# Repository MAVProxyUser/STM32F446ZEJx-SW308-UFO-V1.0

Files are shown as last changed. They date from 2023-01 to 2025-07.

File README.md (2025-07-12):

STM32F446ZEJx UFBGA144 Target Board for ChipWhisperer

* [STM32F446ZEJx-SW308-UFO-V1.0](#stm32f446zejx-sw308-ufo-v10)
   * [Jumpers](#jumpers)
   * [Schematic](#schematic)
   * [Testing Blanks &amp; Real Paprium](#testing-blanks--real-paprium)

It is no secret that I am affiliated with the group of people focusing on [efforts to dump the Watermelon Games Paprium cart](https://github.com/ArcadeHustle/WatermelonPapriumDump). As part of this effort there became a need to 
attack an STM32F4 based chip. Sadly that chip wound up being in RDP2 mode, but the resulting tool that was created serves a greater purpose, so it is being shared here. 

At the time the work effort was put forth there was no UFBGA144 compatible Target Board for ChipWhisperer, so we worked with a trusted PCB design partner [@javier-rodas](https://github.com/javier-rodas) owner of SEVENIX INGENIERIA & the [@XTREME-MISTER](https://github.com/XTREME-MISTER) project to work out what was needed. This board will connect easily to a STLink V2, 
or a ChipWhisperer depending on where the jumpers are placed. The initial project this board was created for never moved past the STLink jumpers, we immediatly found that the chip was fully protected with all debug interfaced 
disabled. 

None the less, this is a perfect platform for learning Chip Whisperer based glitching logic, or attacking other UFBGA144 STM32 chips. 

# STM32F446ZEJx-SW308-UFO-V1.0

[Documentation](https://github.com/MAVProxyUser/STM32F446ZEJx-SW308-UFO-V1.0/tree/main/STM32F446ZEJx-SW308-UFO%20V1.0/DOCS) is fairly simple, set the jumpers accordingly, treat it as you would any other ChipWhisperer target board. 

## Jumpers
Enable jumpers as follows for CW usage. 
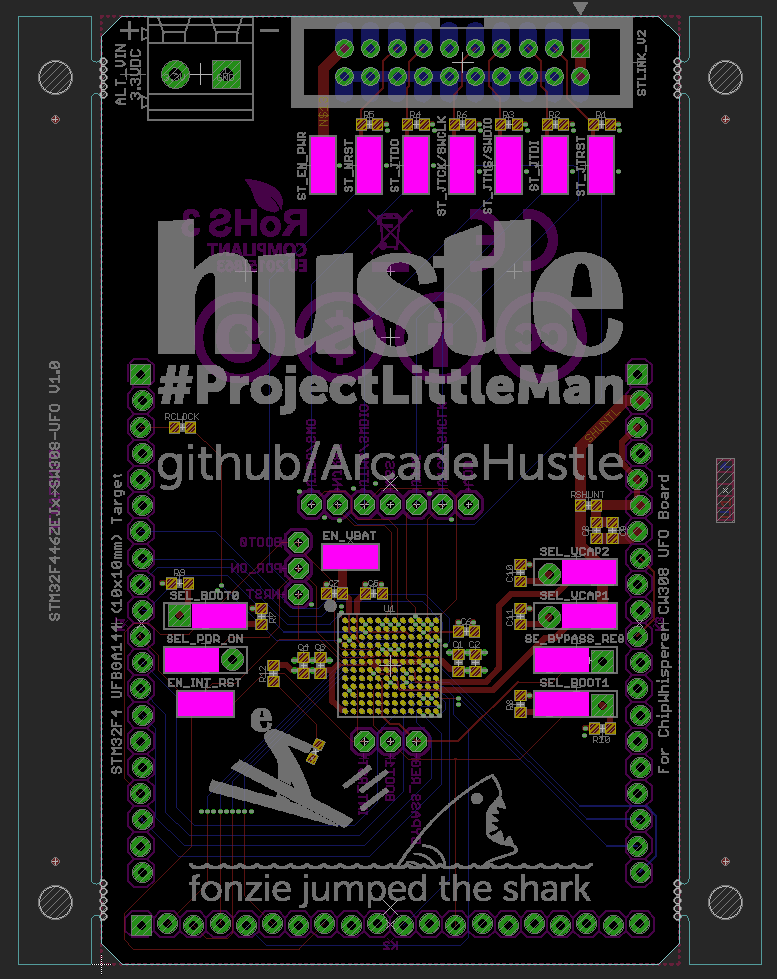
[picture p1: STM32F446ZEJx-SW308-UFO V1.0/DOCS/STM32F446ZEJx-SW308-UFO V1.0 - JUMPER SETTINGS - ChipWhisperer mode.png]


## Schematic
You can see how the jumpers impact the schematic below.  
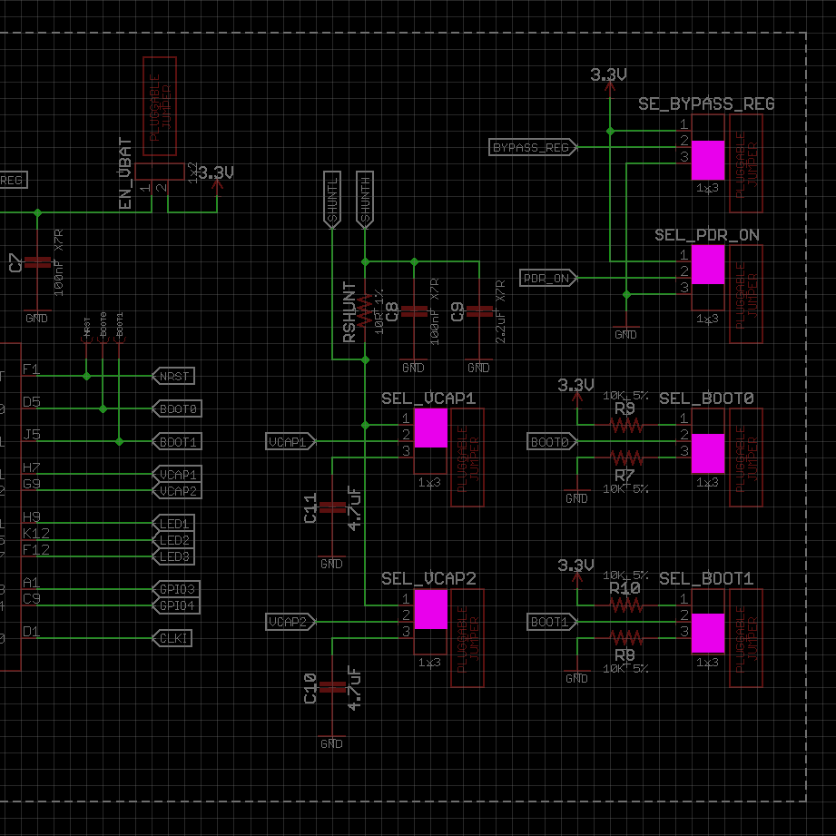
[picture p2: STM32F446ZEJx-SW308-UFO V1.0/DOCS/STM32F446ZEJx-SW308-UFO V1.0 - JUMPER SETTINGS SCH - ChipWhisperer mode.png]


## Testing Blanks & Real Paprium 
We tested this design with a number of now rare blank STM32F446ZEJ6 chips, as well as an excavated STM32 from a Paprium game cart. 
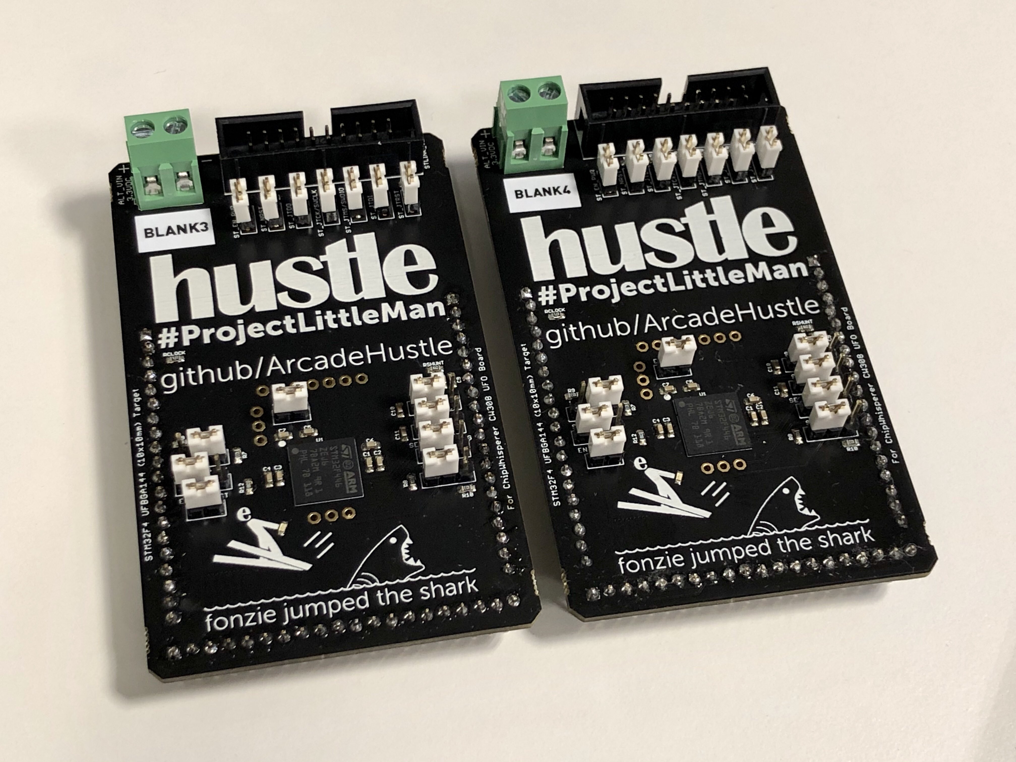
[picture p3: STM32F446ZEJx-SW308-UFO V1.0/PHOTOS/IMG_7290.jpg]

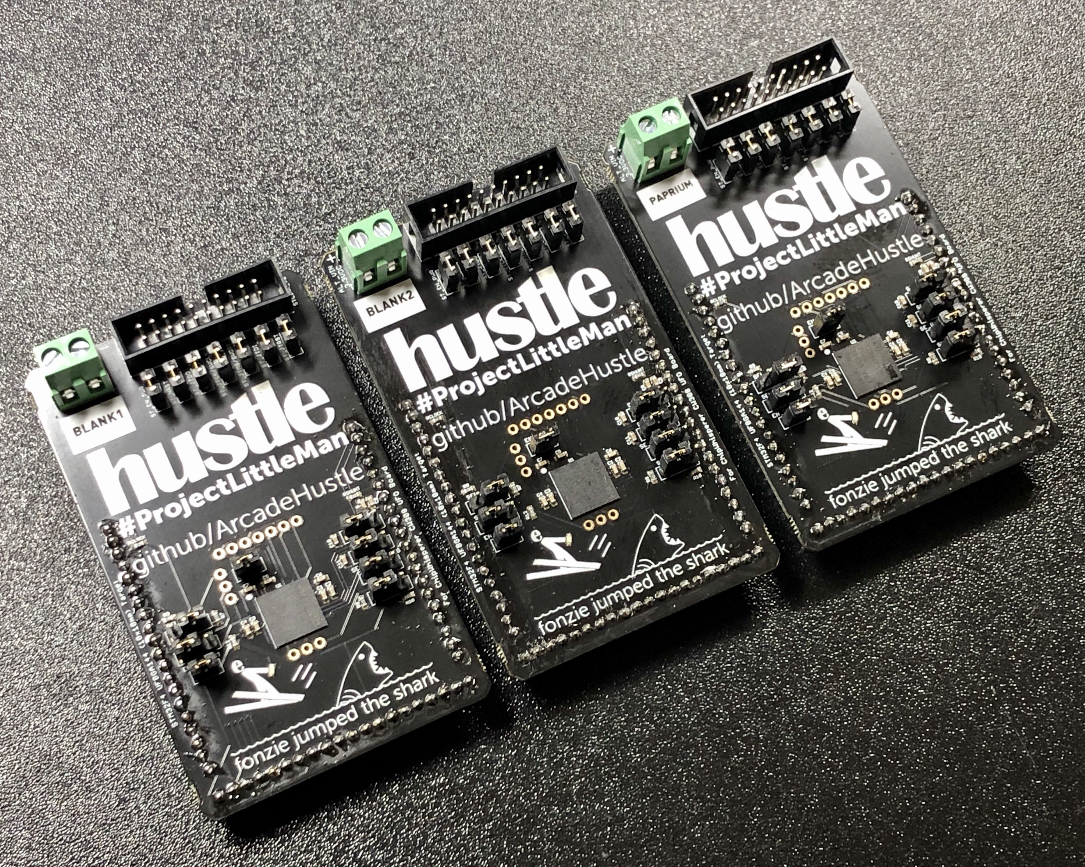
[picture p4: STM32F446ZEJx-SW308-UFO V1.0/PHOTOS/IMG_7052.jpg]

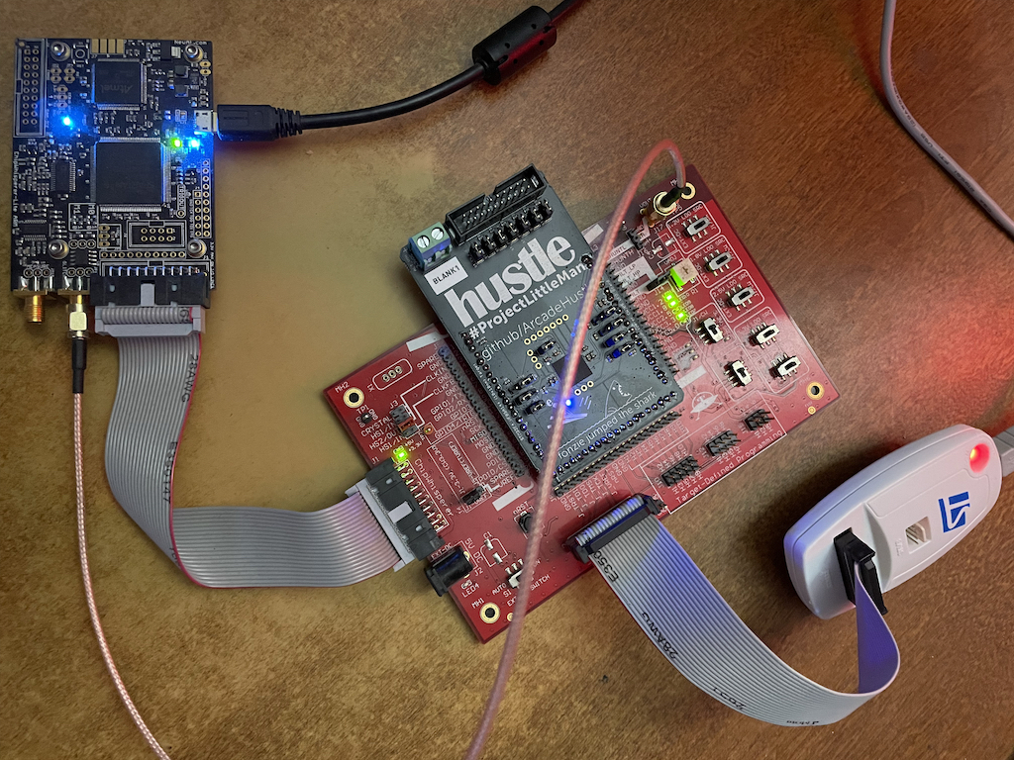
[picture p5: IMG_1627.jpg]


If you need an amazing PCB designer, please let me know, and I can put you in touch with one.

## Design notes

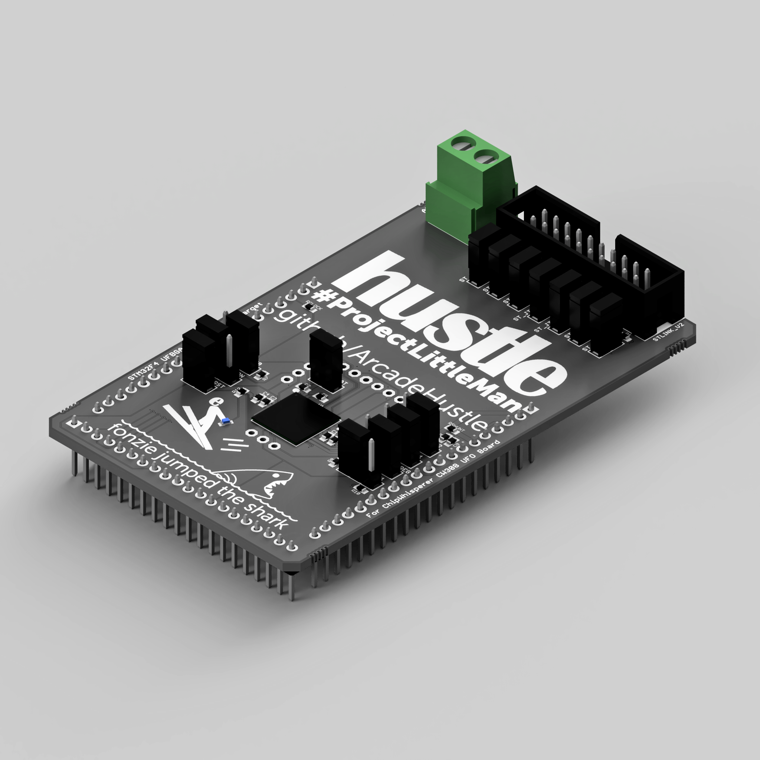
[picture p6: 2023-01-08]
STM32F446ZEJx-SW308-UFO V1.0/RESOURCES/STM32F446ZEJx-SW308-UFO V1.0 - 3.PNG

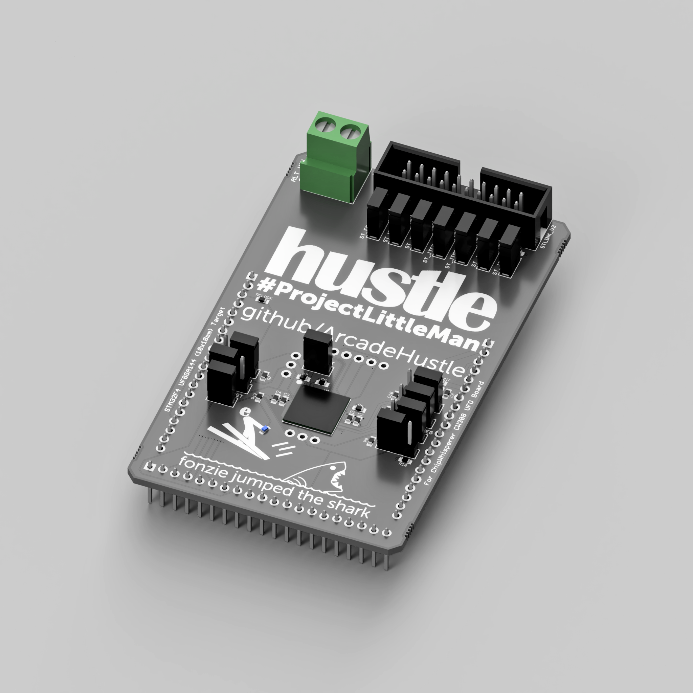
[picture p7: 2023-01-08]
STM32F446ZEJx-SW308-UFO V1.0/RESOURCES/STM32F446ZEJx-SW308-UFO V1.0 - 2.PNG

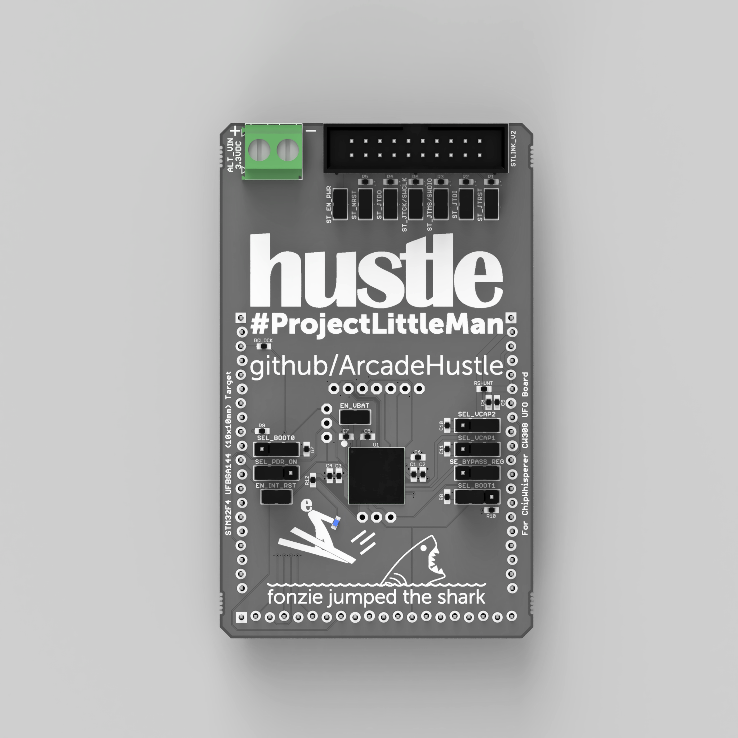
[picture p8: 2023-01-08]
STM32F446ZEJx-SW308-UFO V1.0/RESOURCES/STM32F446ZEJx-SW308-UFO V1.0 - 1.PNG

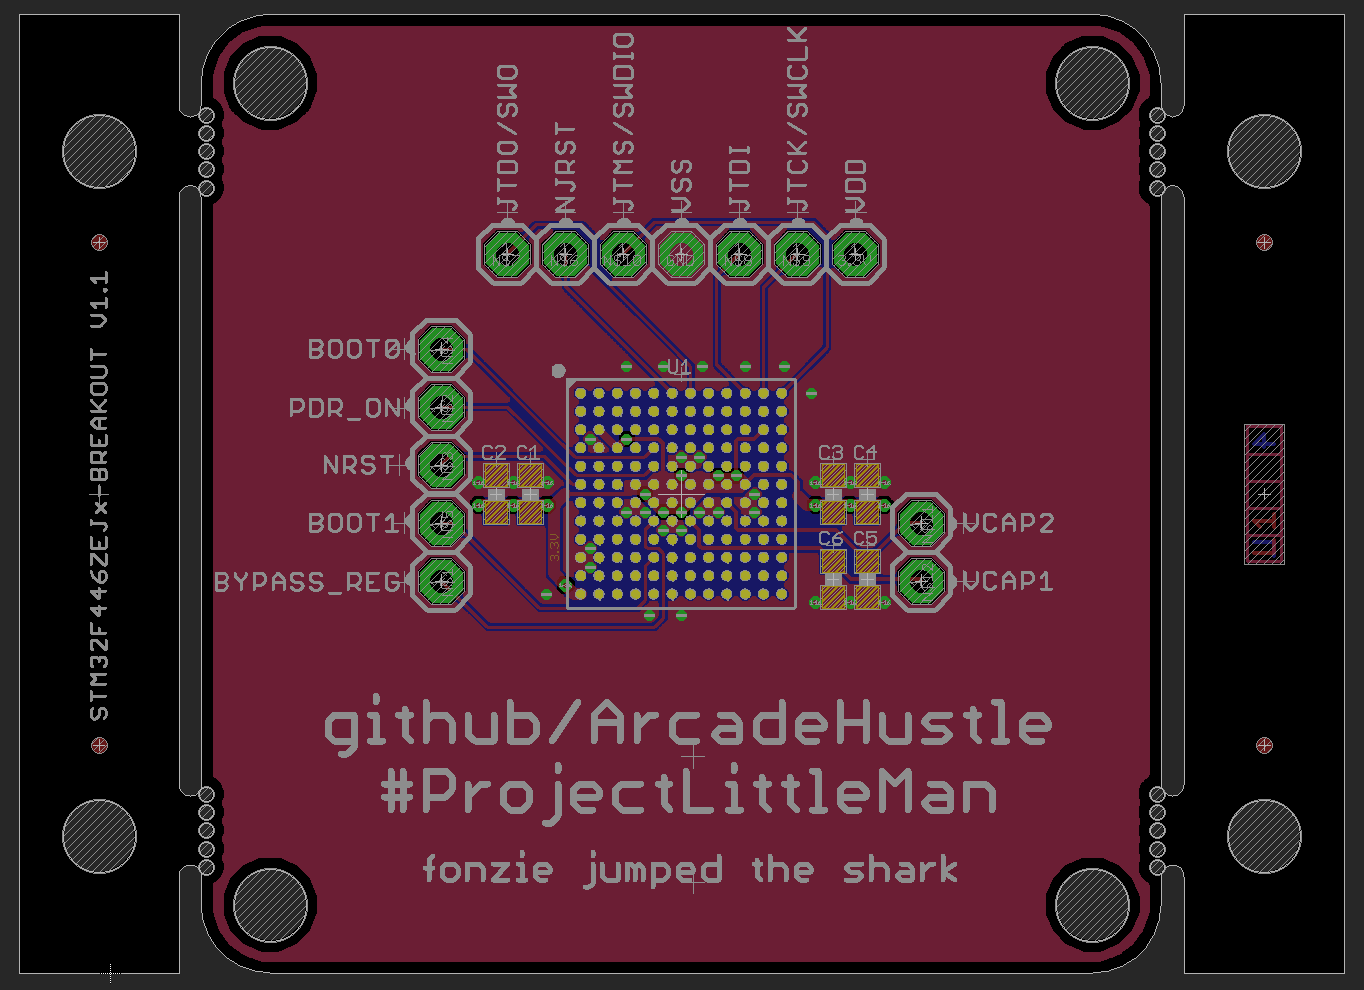
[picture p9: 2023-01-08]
failed_attempts/STM32F446ZEJx-BREAKOUT V1.1/STM32F446ZEJx-BREAKOUT V1.1 - PREVIEW.png

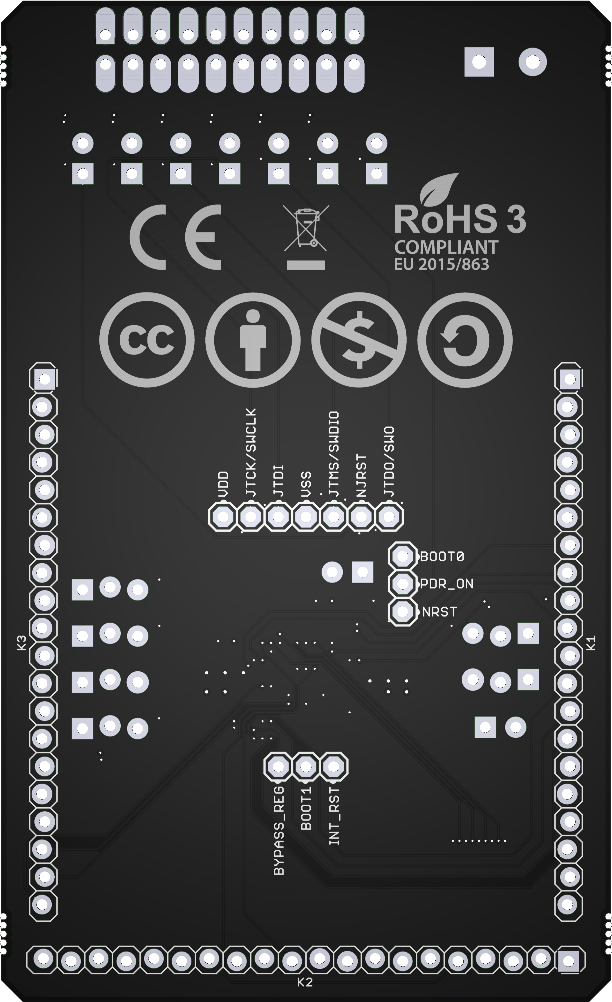
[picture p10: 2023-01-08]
STM32F446ZEJx-SW308-UFO V1.0/RESOURCES/STM32F446ZEJx-SW308-UFO V1.0 - PREVIEW BOTTOM.png

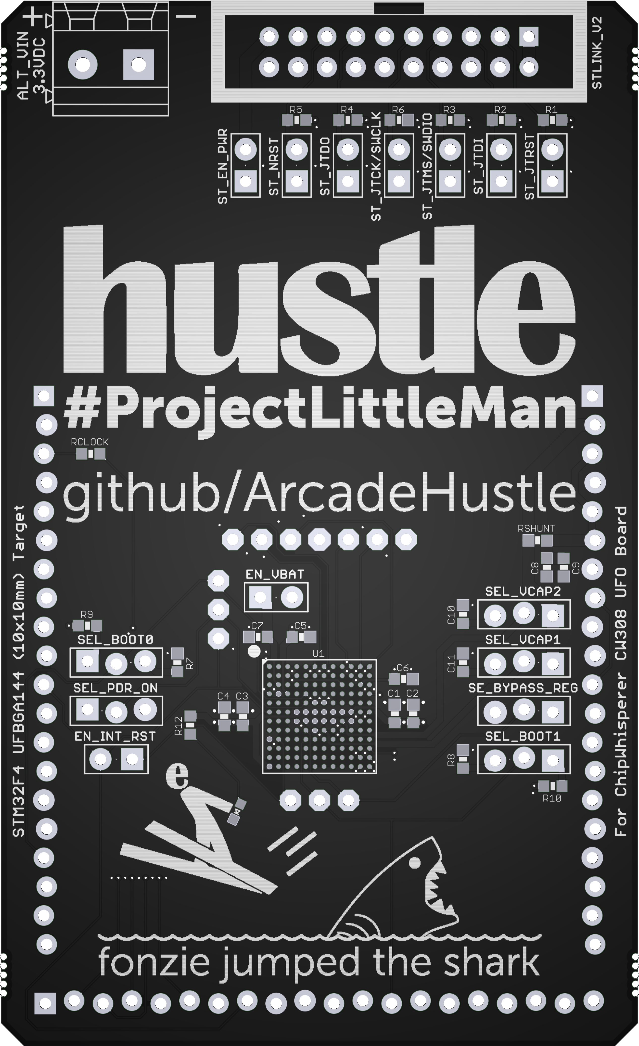
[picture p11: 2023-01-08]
STM32F446ZEJx-SW308-UFO V1.0/RESOURCES/STM32F446ZEJx-SW308-UFO V1.0 - PREVIEW TOP.png

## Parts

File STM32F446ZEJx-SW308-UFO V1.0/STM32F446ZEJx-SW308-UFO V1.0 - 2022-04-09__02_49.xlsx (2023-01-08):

PROJECT NAME |  | STM32F446ZEJx-SW308-UFO V1.0
REVISION DATE |  | 2022-09-04 02:49
Qt (req.) | Min\Mult Order Qty | Qt (min) | Unit Price (USD) | Order Req. Price (USD) | Order Min. Price (USD) | Quantity Available (4/9/2022) | LCSC_PN | Minimum Specification | Package | RoHS | Manufacturer | Manufacturer Part Number | Designator
8 | 100\100 | 100 | $0.0028 | $0.0224 | $0.2800 | 25988600 | C1591 | 100nF X7R | 0603_IPC_NOMINAL | Y | Samsung Electro-Mechanics | CL10B104KB8NNNC | C1, C2, C3, C4, C5, C6, C7, C8
10 | 100\100 | 100 | $0.0011 | $0.0110 | $0.1100 | 33697600 | C99198 | 10K 5% | 0603_IPC_NOMINAL | Y | YAGEO | RC0603JR-0710KL | R1, R2, R3, R4, R5, R6, R7, R8, R9, R10
1 | 100\100 | 100 | $0.0012 | $0.0012 | $0.1200 | 881600 | C109318 | 10R 1% | 0603_IPC_NOMINAL | Y | YAGEO | RC0603FR-0710RL | RSHUNT
1 | 100\100 | 100 | $0.0014 | $0.0014 | $0.1400 | 7905100 | C22548 | 1K | 0603_IPC_NOMINAL | Y | YAGEO | RC0603FR-071KL | R12
9 | 20\20 | 20 | $0.0282 | $0.2538 | $0.5640 | 34260 | C124375 | 1x2 | M1X2 | Y | Ckmtw(Shenzhen Cankemeng) | C124375 | EN_INT_RST, EN_VBAT, ST_EN_PWR, ST_JTCK/SWCLK, ST_JTDI, ST_JTDO, ST_JTMS/SWDIO, ST_JTRST, ST_NRST
3 | 5\5 | 5 | $0.1047 | $0.3141 | $0.5235 | 15930 | C50981 | 1x20 | M1X20 | Y | BOOMELE(Boom Precision Elec) | C50981 | K1, K2, K3
6 | 50\50 | 50 | $0.0148 | $0.0888 | $0.7400 | 100 | C49257 | 1x3 | M1X3 | Y | BOOMELE(Boom Precision Elec) | C49257 | SEL_BOOT0, SEL_BOOT1, SEL_PDR_ON, SEL_VCAP1, SEL_VCAP2, SE_BYPASS_REG
1 | 50\50 | 50 | $0.0150 | $0.0150 | $0.7500 | 284250 | C100082 | 2.2uF X7R | 0603_IPC_NOMINAL | Y | Samsung Electro-Mechanics | CL10B225KP8NNNC | C9
1 | 5\5 | 5 | $0.1239 | $0.1239 | $0.6195 | 53305 | C8465 | 2P_5.08MM | 2X5.08MM | Y | Ningbo Kangnex Elec | WJ500V-5.08-2P | ALT_VIN
2 | 50\50 | 50 | $0.0042 | $0.0084 | $0.2100 | 7109400 | C8032 | 4.7uF X5R | 0603_IPC_NOMINAL | Y | Samsung Electro-Mechanics | CL10A475KQ8NNNC | C10, C11
1 | 100\100 | 100 | $0.0013 | $0.0013 | $0.1300 | 584800 | C114628 | 51R 1% | 0603_IPC_NOMINAL | Y | YAGEO | RC0603FR-0751RL | RCLOCK
1 | 20\20 | 20 | $0.0209 | $0.0209 | $0.4180 | 260520 | C72041 | BLUE | 0603-BLUE-LED | Y | Everlight Elec | 19-217/BHC-ZL1M2RY/3T | PWR
1 | 5\5 | 5 | $0.0976 | $0.0976 | $0.4880 | 8905 | C429961 | IDC20 | M2X10_2.54MM_IDC_SHROUDED | Y | JLIN | 321020SG0ABK00A01 | STLINK_V2
15 | 50\50 | 50 | $0.0076 | $0.1140 | $0.3800 | 910600 | C5305 | JUMPER_2.54MM | JUMPER_2.54MM | Y | BOOMELE(Boom Precision Elec) | C5305 | JUMPER1, JUMPER2, JUMPER3, JUMPER4, JUMPER5, JUMPER6, JUMPER7, JUMPER8, JUMPER9, JUMPER10, JUMPER11, JUMPER12, JUMPER13, JUMPER14, JUMPER15
 |  | 1 | $3.0000 |  | $3.0000 |  |  | Handling fee (order <$18)
 |  |  |  | $1.07 | $8.47
 |  |  |  |  | $43.70 | DHL Express shipping (3-7 days)
 |  |  |  |  | $52.17 | TOTAL

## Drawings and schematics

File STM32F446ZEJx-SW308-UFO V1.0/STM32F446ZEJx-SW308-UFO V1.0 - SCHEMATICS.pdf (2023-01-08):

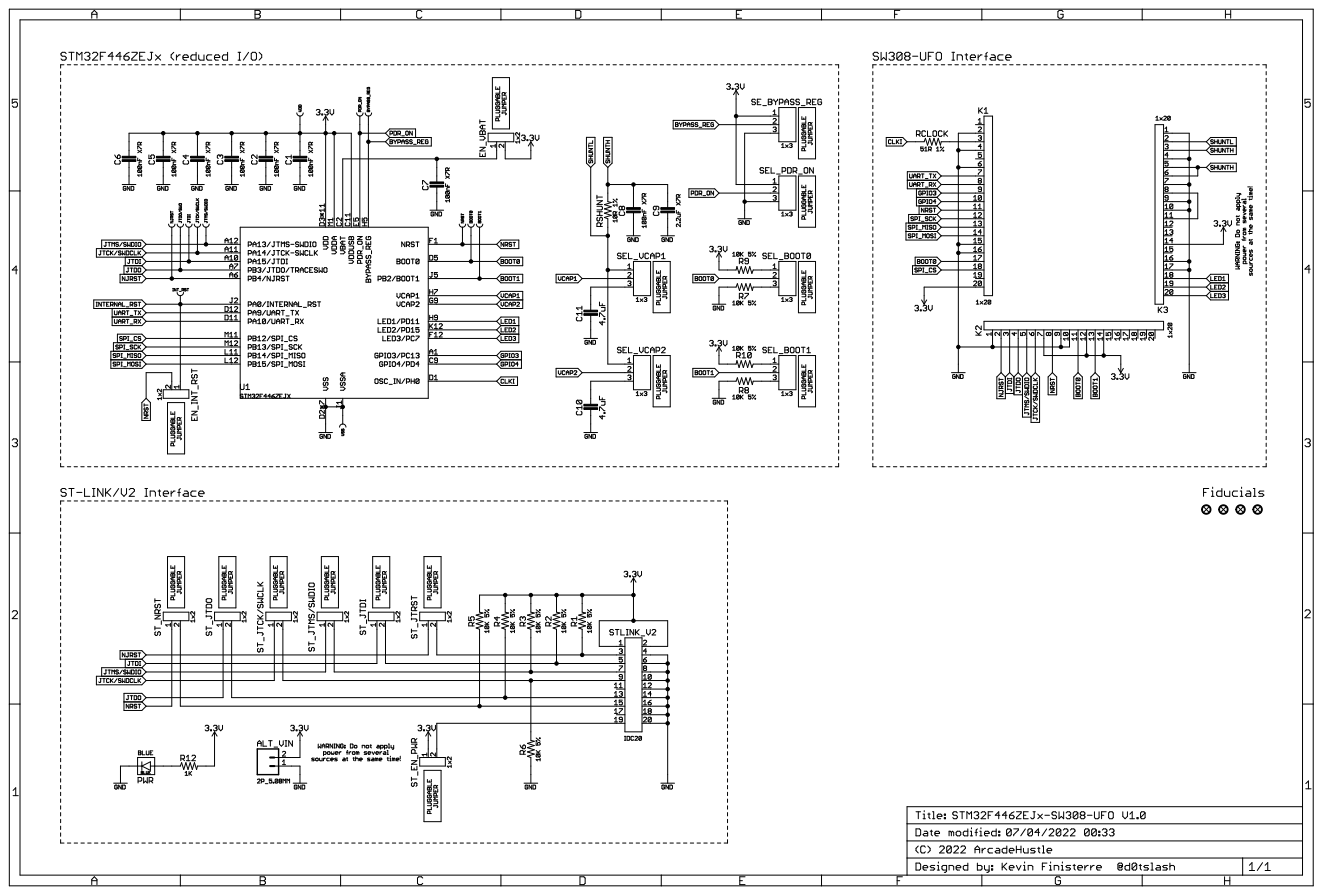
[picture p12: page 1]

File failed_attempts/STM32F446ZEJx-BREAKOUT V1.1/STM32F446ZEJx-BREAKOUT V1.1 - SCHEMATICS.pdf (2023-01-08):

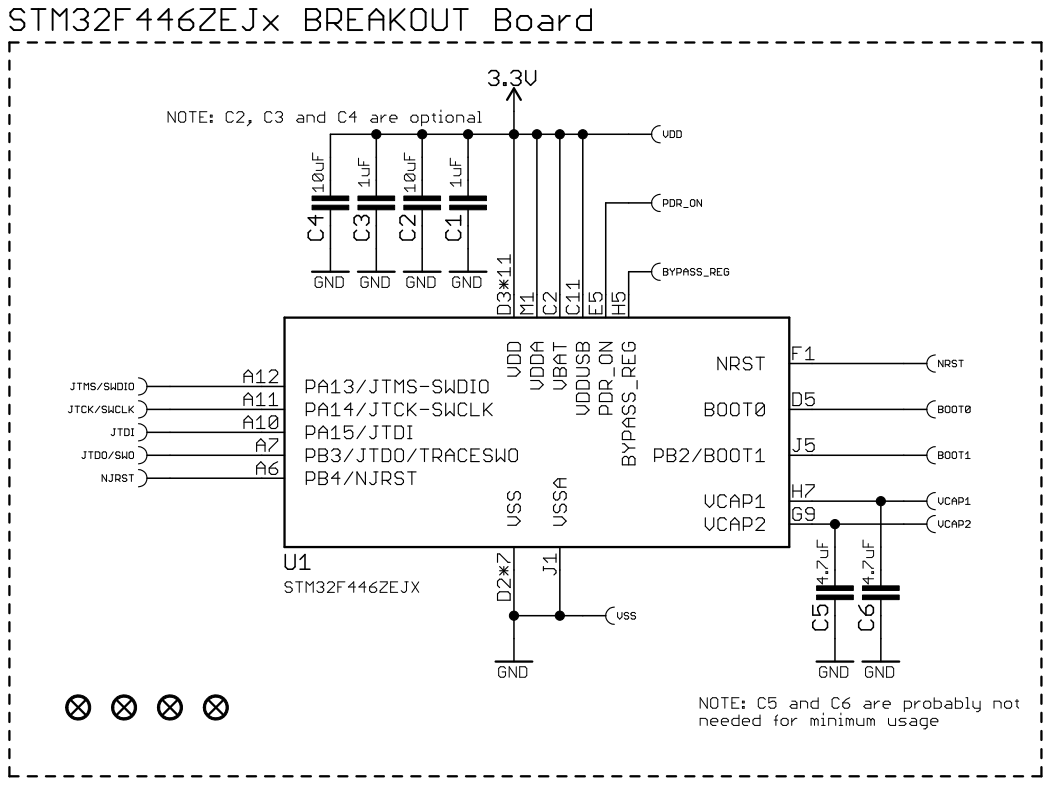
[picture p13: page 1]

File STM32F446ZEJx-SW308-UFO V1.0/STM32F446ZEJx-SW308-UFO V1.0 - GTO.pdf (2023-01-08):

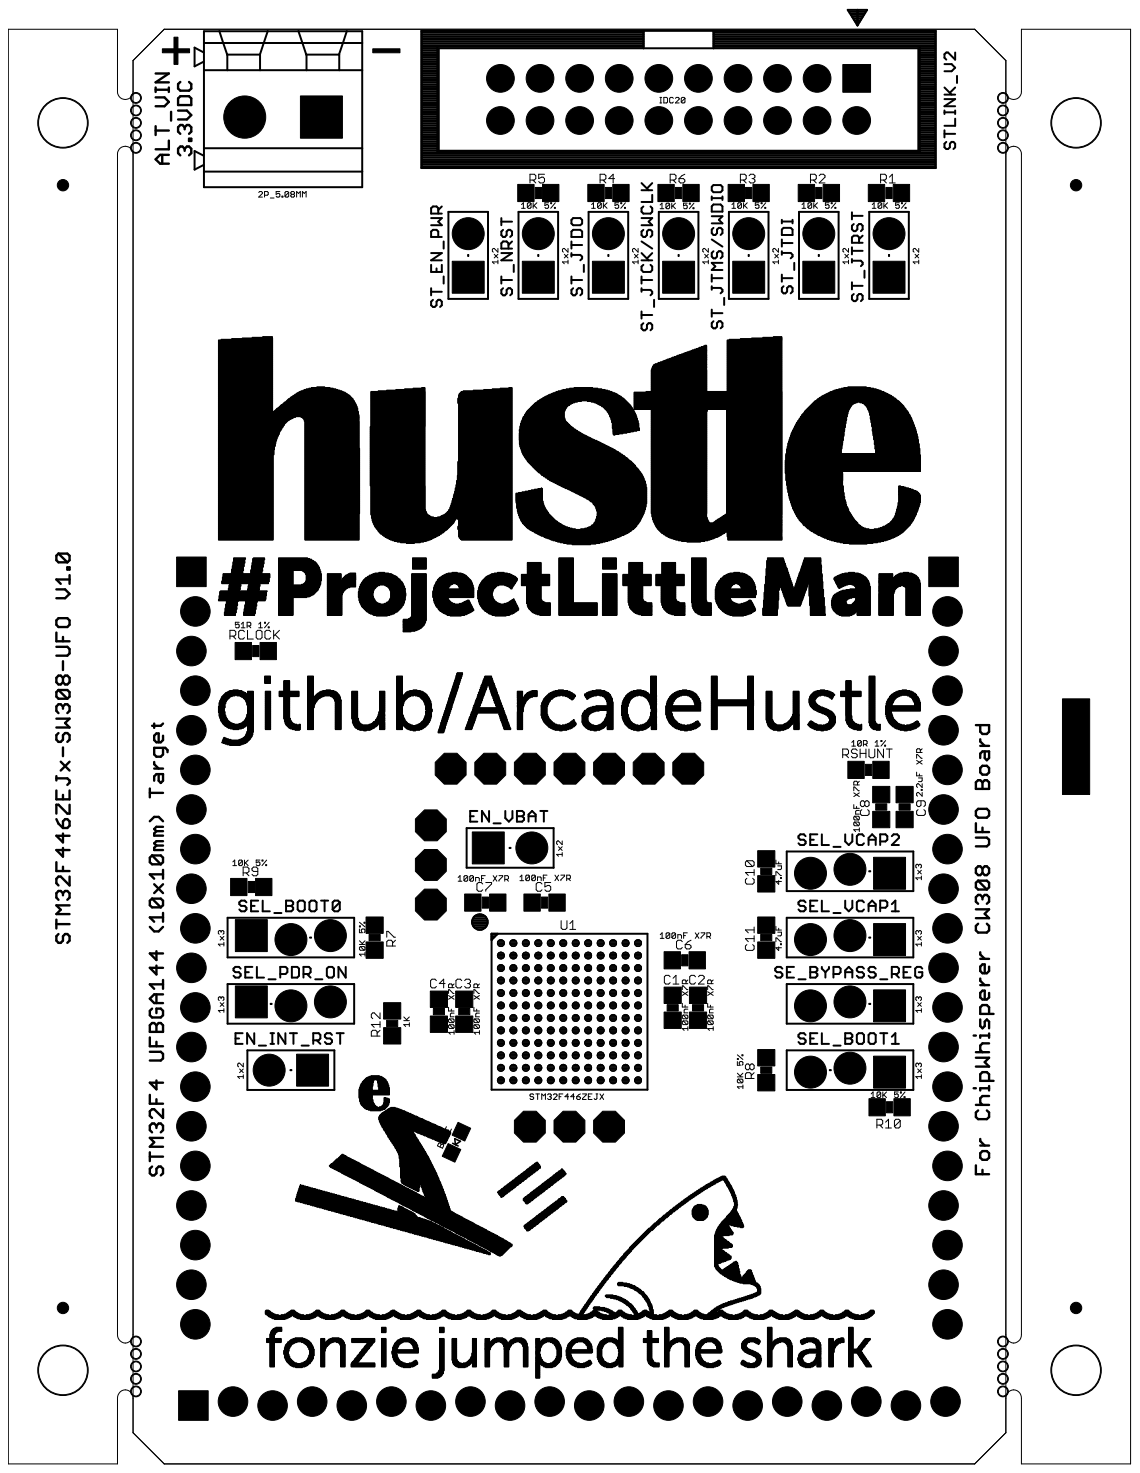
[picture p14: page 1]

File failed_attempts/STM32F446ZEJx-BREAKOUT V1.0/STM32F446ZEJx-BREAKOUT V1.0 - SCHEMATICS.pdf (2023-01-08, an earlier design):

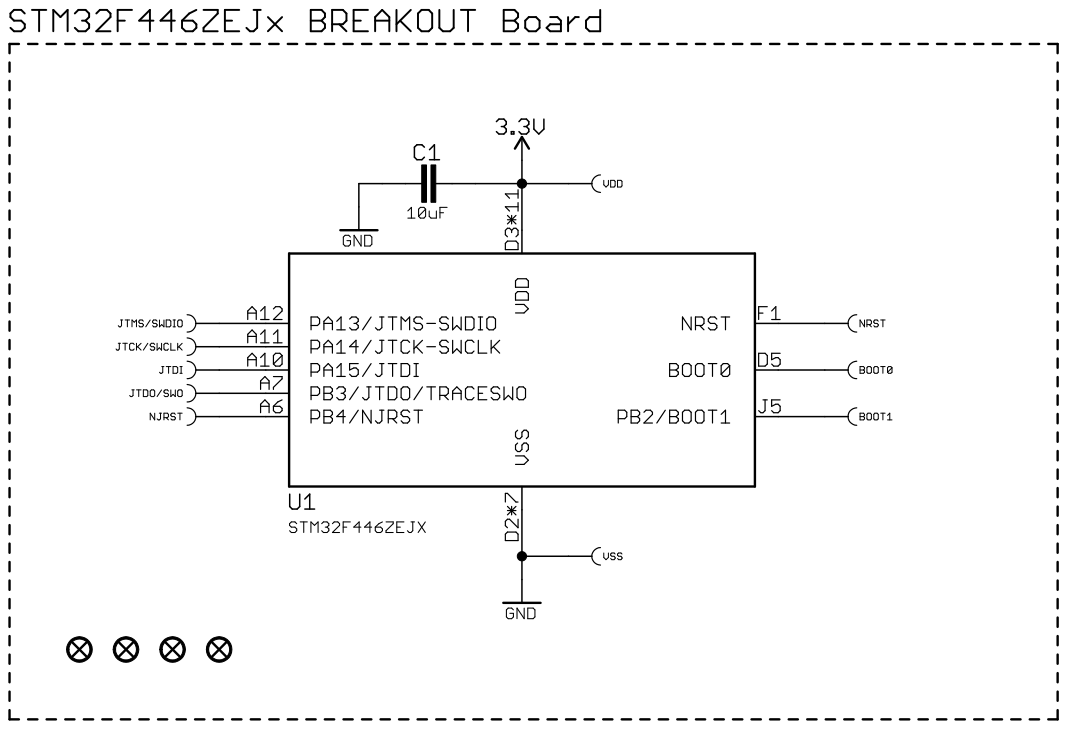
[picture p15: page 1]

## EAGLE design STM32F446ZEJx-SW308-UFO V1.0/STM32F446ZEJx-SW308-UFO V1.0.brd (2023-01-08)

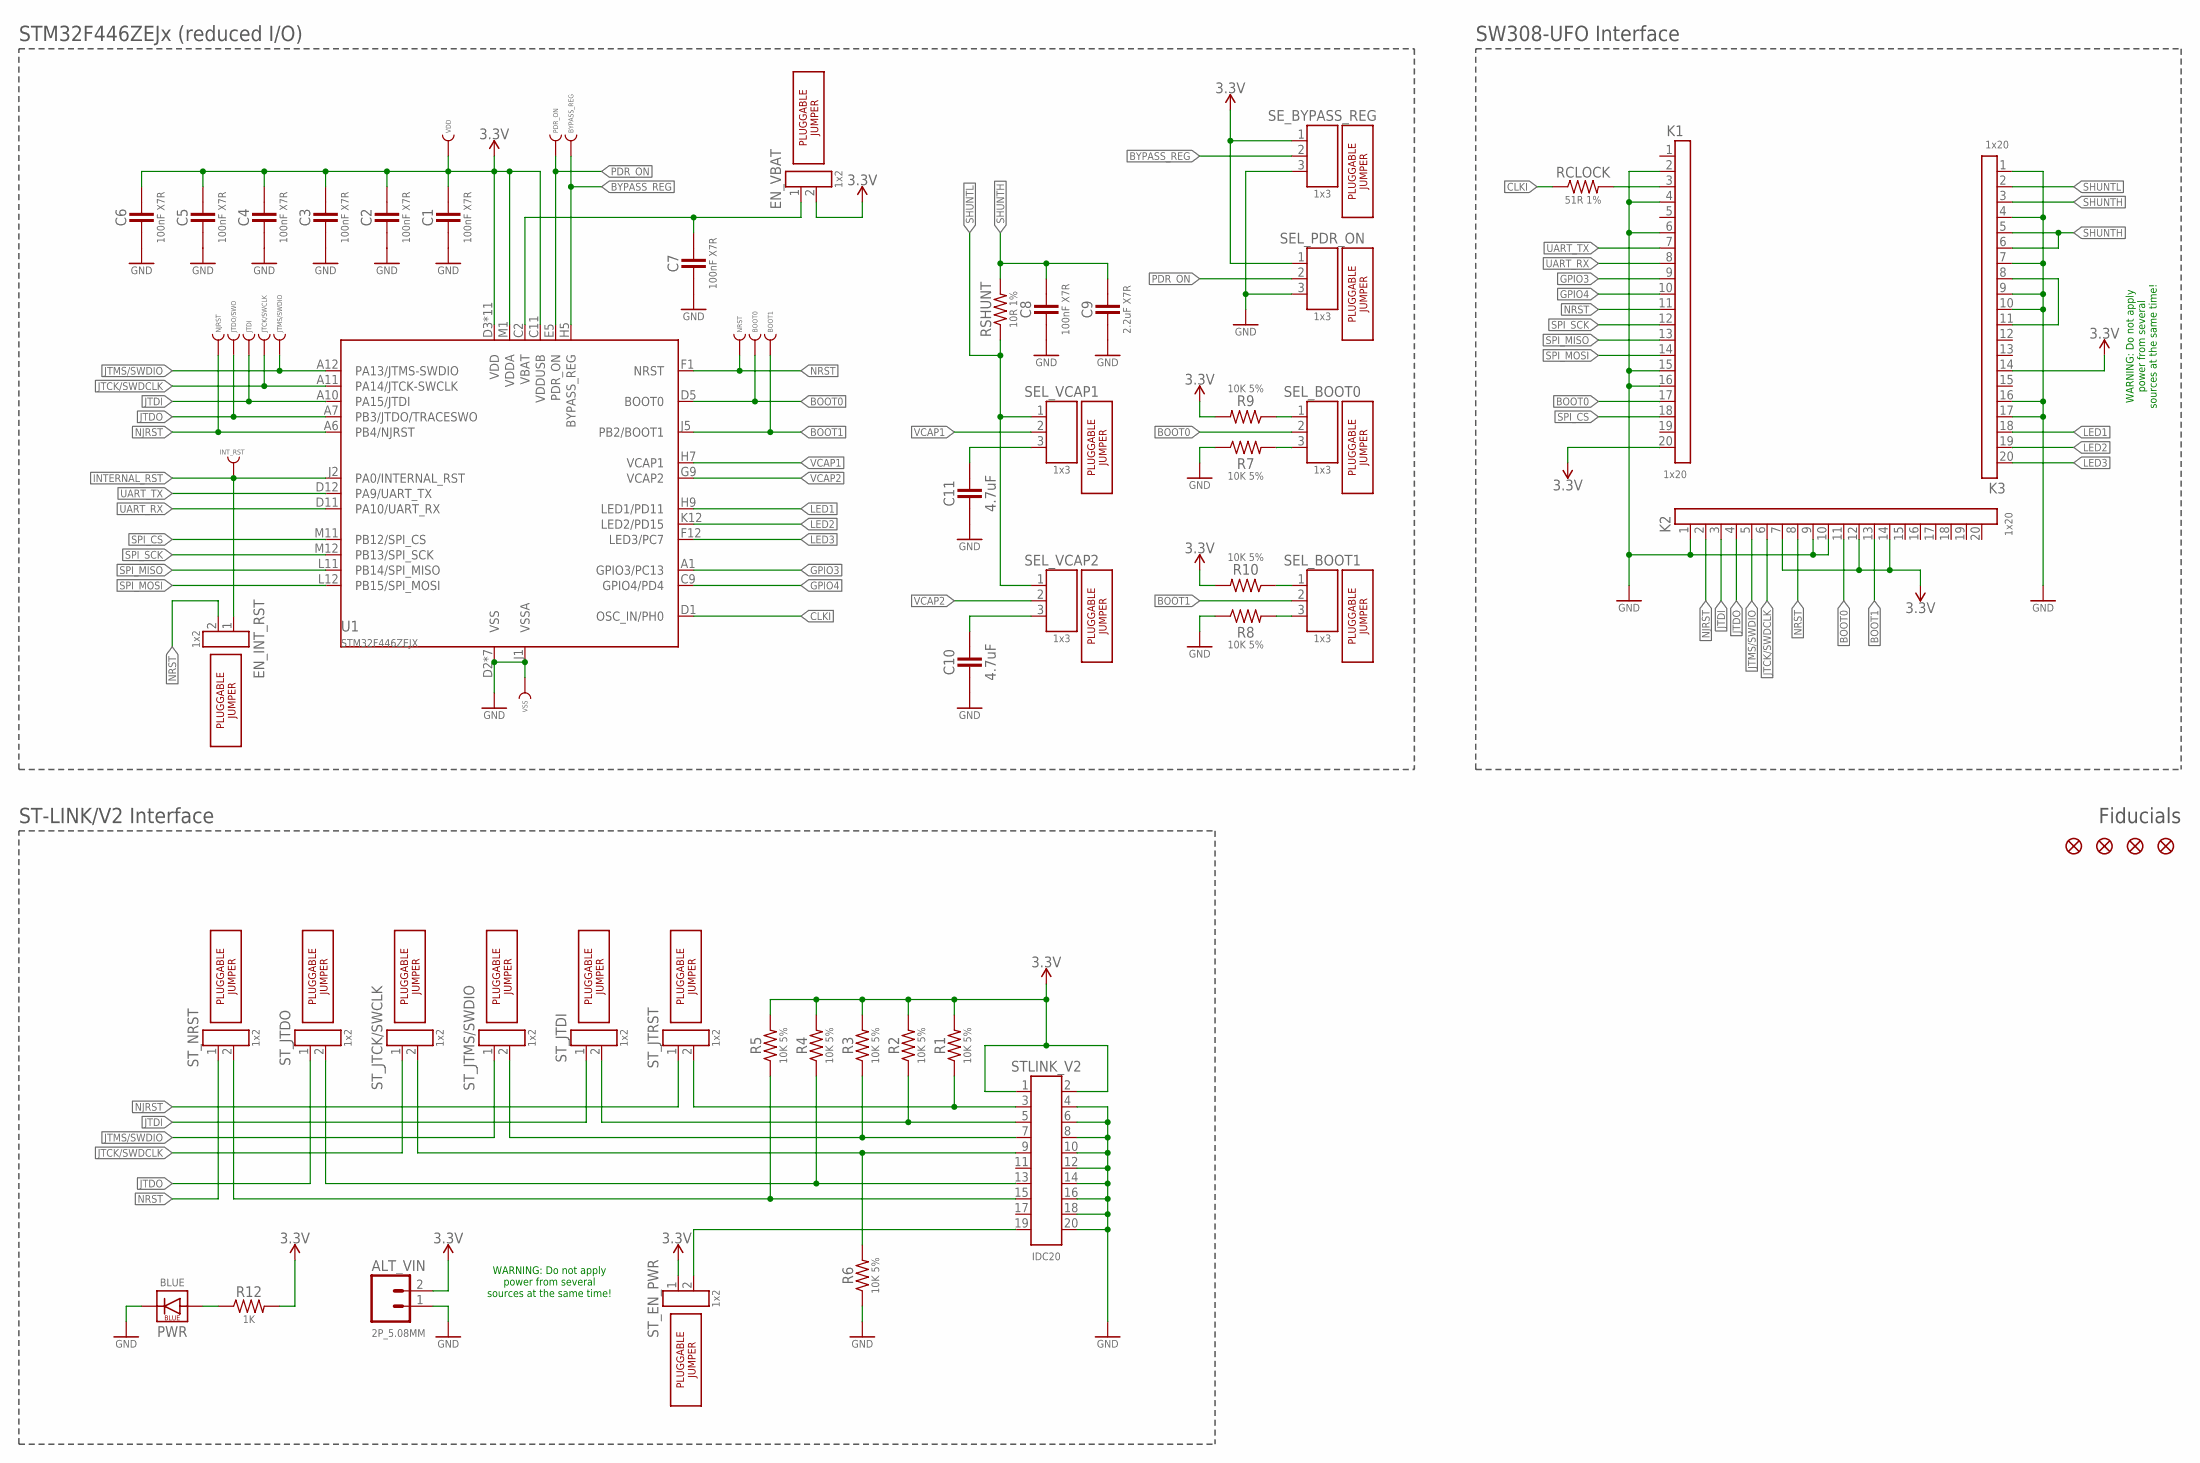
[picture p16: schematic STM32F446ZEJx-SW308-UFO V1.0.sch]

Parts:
ALT_VIN: 2P_5.08MM; BORNA_2X5.08MM_NINGBO-KANGNEX-ELEC_WJ500V-5.08-2P
BOOT0, BOOT1: TESTPOINT_TH_0.8MM; 1X01
BYPASS_REG: TESTPOINT_TH_0.8MM; 1X01
C1, C2, C3, C4, C5, C6, C7, C8: 100nF X7R; 0603_IPC_NOMINAL; LCSC_PN C1591
C9: 2.2uF X7R; 0603_IPC_NOMINAL; LCSC_PN C100082
C10, C11: 4.7uF; 0603_IPC_NOMINAL; LCSC_PN C8032
EN_INT_RST: 1x2; M1X2_GREENCONN_GPHA101-0201A001A1BA(A=6,B=3)_ALT_PADS
EN_VBAT: 1x2; M1X2_GREENCONN_GPHA101-0201A001A1BA(A=6,B=3)_ALT_PADS
FD1, FD5, FD7, FD9: FIDUCIAL_MICRO; FIDUCIAL-MICRO
INT_RST: TESTPOINT_TH_0.8MM; 1X01
JTCK/SWCLK: TESTPOINT_TH_0.8MM; 1X01
JTDI: TESTPOINT_TH_0.8MM; 1X01
JTDO/SWO: TESTPOINT_TH_0.8MM; 1X01
JTMS/SWDIO: TESTPOINT_TH_0.8MM; 1X01
JUMPER1, JUMPER2, JUMPER3, JUMPER4, JUMPER5, JUMPER6, JUMPER7, JUMPER8, JUMPER9, JUMPER10, JUMPER11, JUMPER12, JUMPER13, JUMPER14, JUMPER15: JUMPER_2.54MM
K1, K2, K3: 1x20; M1X20_2.54MM_LOCK_BOOMELE_C50981
NJRST: TESTPOINT_TH_0.8MM; 1X01
NRST: TESTPOINT_TH_0.8MM; 1X01
PDR_ON: TESTPOINT_TH_0.8MM; 1X01
PWR: BLUE; 0603-BLUE-LED
R1, R2, R3, R4, R5, R6, R7, R8, R9, R10: 10K 5%; 0603_IPC_NOMINAL; LCSC_PN C99198
R12: 1K; 0603_IPC_NOMINAL; LCSC_PN C22548
RCLOCK: 51R 1%; 0603_IPC_NOMINAL; LCSC_PN C114628
RSHUNT: 10R 1%; 0603_IPC_NOMINAL; LCSC_PN C109318
SEL_BOOT0, SEL_BOOT1: 1x3; M1X3_GREENCONN_GPHA101-0301A001A1BA(A=6,B=3)_ALT_PADS
SEL_PDR_ON: 1x3; M1X3_GREENCONN_GPHA101-0301A001A1BA(A=6,B=3)_ALT_PADS
SEL_VCAP1, SEL_VCAP2: 1x3; M1X3_GREENCONN_GPHA101-0301A001A1BA(A=6,B=3)_ALT_PADS
SE_BYPASS_REG: 1x3; M1X3_GREENCONN_GPHA101-0301A001A1BA(A=6,B=3)_ALT_PADS
STLINK_V2: IDC20; M2X10_2.54MM_IDC_SHROUDED__JLIN_321020SG0ABK00A01_C429961
ST_EN_PWR: 1x2; M1X2_GREENCONN_GPHA101-0201A001A1BA(A=6,B=3)_ALT_PADS
ST_JTCK/SWCLK: 1x2; M1X2_GREENCONN_GPHA101-0201A001A1BA(A=6,B=3)_ALT_PADS
ST_JTDI: 1x2; M1X2_GREENCONN_GPHA101-0201A001A1BA(A=6,B=3)_ALT_PADS
ST_JTDO: 1x2; M1X2_GREENCONN_GPHA101-0201A001A1BA(A=6,B=3)_ALT_PADS
ST_JTMS/SWDIO: 1x2; M1X2_GREENCONN_GPHA101-0201A001A1BA(A=6,B=3)_ALT_PADS
ST_JTRST: 1x2; M1X2_GREENCONN_GPHA101-0201A001A1BA(A=6,B=3)_ALT_PADS
ST_NRST: 1x2; M1X2_GREENCONN_GPHA101-0201A001A1BA(A=6,B=3)_ALT_PADS
U1: STM32F446ZEJX
VDD: TESTPOINT_TH_0.8MM; 1X01
VSS: TESTPOINT_TH_0.8MM; 1X01

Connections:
3.3V: ALT_VIN.2, C1.1, C2.1, C3.1, C4.1, C5.1, C6.1, EN_VBAT.2, K1.20, K2.7, K2.12, K2.14, K3.14, R1.2, R2.2, R3.2, R4.2, R5.2, R9.2, R10.2, R12.2, SEL_PDR_ON.1, SE_BYPASS_REG.1, STLINK_V2.1, STLINK_V2.2, ST_EN_PWR.1, U1.C11 (VDDUSB), U1.D3 (VDD), U1.F4 (VDD), U1.F5 (VDD), U1.F6 (VDD), U1.F7 (VDD), U1.F8 (VDD), U1.F9 (VDD), U1.F10 (VDD), U1.G5 (VDD), U1.G6 (VDD), U1.G7 (VDD), U1.M1 (VDDA), VDD.1
BOOT0: BOOT0.1, K1.17, K2.11, SEL_BOOT0.2, U1.D5 (BOOT0)
BOOT1: BOOT1.1, K2.13, SEL_BOOT1.2, U1.J5 (PB2/BOOT1)
BYPASS_REG: BYPASS_REG.1, SE_BYPASS_REG.2, U1.H5 (BYPASS_REG)
CLKI: RCLOCK.1, U1.D1 (OSC_IN/PH0)
GND: ALT_VIN.1, C1.2, C2.2, C3.2, C4.2, C5.2, C6.2, C7.2, C8.2, C9.2, C10.2, C11.2, K1.2, K1.4, K1.6, K1.15, K1.16, K2.1, K2.9, K2.10, K3.1, K3.4, K3.7, K3.9, K3.10, K3.16, K3.17, PWR.CATHODE (C), R6.1, R7.1, R8.1, SEL_PDR_ON.3, SE_BYPASS_REG.3, STLINK_V2.4, STLINK_V2.6, STLINK_V2.8, STLINK_V2.10, STLINK_V2.12, STLINK_V2.14, STLINK_V2.16, STLINK_V2.18, STLINK_V2.20, U1.D2 (VSS), U1.E6 (VSS), U1.E7 (VSS), U1.G4 (VSS), U1.G8 (VSS), U1.G10 (VSS), U1.H6 (VSS), U1.J1 (VSSA), VSS.1
GPIO3: K1.9, U1.A1 (GPIO3/PC13)
GPIO4: K1.10, U1.C9 (GPIO4/PD4)
INTERNAL_RST: EN_INT_RST.1, INT_RST.1, U1.J2 (PA0/INTERNAL_RST)
JTCK/SWDCLK: JTCK/SWCLK.1, K2.6, ST_JTCK/SWCLK.1, U1.A11 (PA14/JTCK-SWCLK)
JTDI: JTDI.1, K2.3, ST_JTDI.1, U1.A10 (PA15/JTDI)
JTDO: JTDO/SWO.1, K2.4, ST_JTDO.1, U1.A7 (PB3/JTDO/TRACESWO)
JTMS/SWDIO: JTMS/SWDIO.1, K2.5, ST_JTMS/SWDIO.1, U1.A12 (PA13/JTMS-SWDIO)
LED1: K3.18, U1.H9 (LED1/PD11)
LED2: K3.19, U1.K12 (LED2/PD15)
LED3: K3.20, U1.F12 (LED3/PC7)
unnamed: R2.1, STLINK_V2.5, ST_JTDI.2
unnamed: C7.1, EN_VBAT.1, U1.C2 (VBAT)
unnamed: PWR.ANODE (A), R12.1
unnamed: R3.1, STLINK_V2.7, ST_JTMS/SWDIO.2
unnamed: C10.1, SEL_VCAP2.3
unnamed: R1.1, STLINK_V2.3, ST_JTRST.2
unnamed: R6.2, STLINK_V2.9, ST_JTCK/SWCLK.2
unnamed: R7.2, SEL_BOOT0.3
unnamed: R4.1, STLINK_V2.13, ST_JTDO.2
unnamed: R10.1, SEL_BOOT1.1
unnamed: R5.1, STLINK_V2.15, ST_NRST.2
unnamed: R8.2, SEL_BOOT1.3
unnamed: STLINK_V2.19, ST_EN_PWR.2
unnamed: C11.1, SEL_VCAP1.3
unnamed: R9.1, SEL_BOOT0.1
unnamed: K3.8, K3.11
unnamed: K1.3, RCLOCK.2
NJRST: K2.2, NJRST.1, ST_JTRST.1, U1.A6 (PB4/NJRST)
NRST: EN_INT_RST.2, K1.11, K2.8, NRST.1, ST_NRST.1, U1.F1 (NRST)
PDR_ON: PDR_ON.1, SEL_PDR_ON.2, U1.E5 (PDR_ON)
SHUNTH: C8.1, C9.1, K3.3, K3.5, K3.6, RSHUNT.2
SHUNTL: K3.2, RSHUNT.1, SEL_VCAP1.1, SEL_VCAP2.1
SPI_CS: K1.18, U1.M11 (PB12/SPI_CS)
SPI_MISO: K1.13, U1.L11 (PB14/SPI_MISO)
SPI_MOSI: K1.14, U1.L12 (PB15/SPI_MOSI)
SPI_SCK: K1.12, U1.M12 (PB13/SPI_SCK)
UART_RX: K1.8, U1.D11 (PA10/UART_RX)
UART_TX: K1.7, U1.D12 (PA9/UART_TX)
VCAP1: SEL_VCAP1.2, U1.H7 (VCAP1)
VCAP2: SEL_VCAP2.2, U1.G9 (VCAP2)

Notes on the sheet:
STM32F446ZEJx (reduced I/O)
ST-LINK/V2 Interface
WARNING: Do not apply power from several sources at the same time!
SW308-UFO Interface
Fiducials

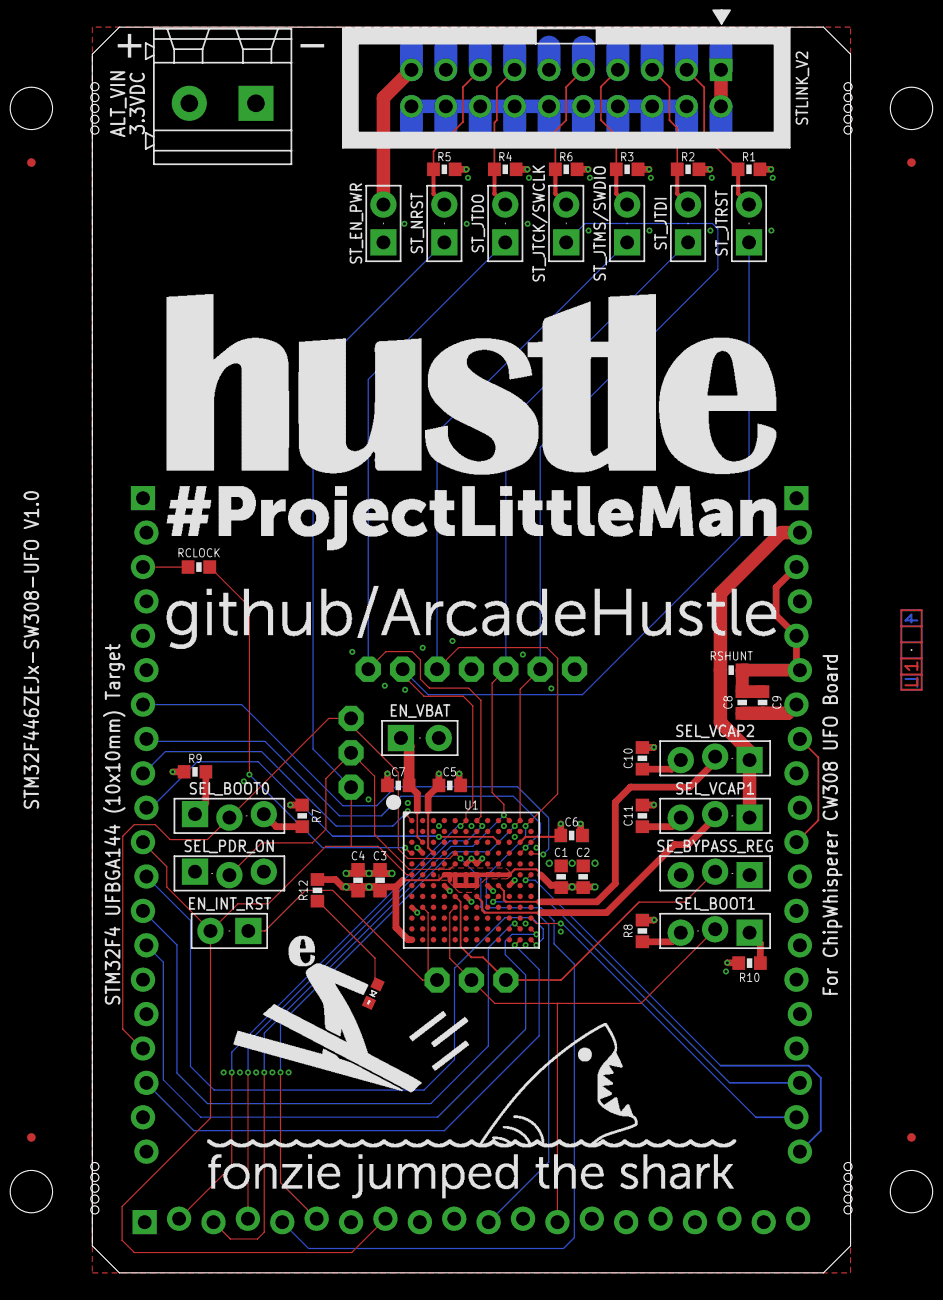
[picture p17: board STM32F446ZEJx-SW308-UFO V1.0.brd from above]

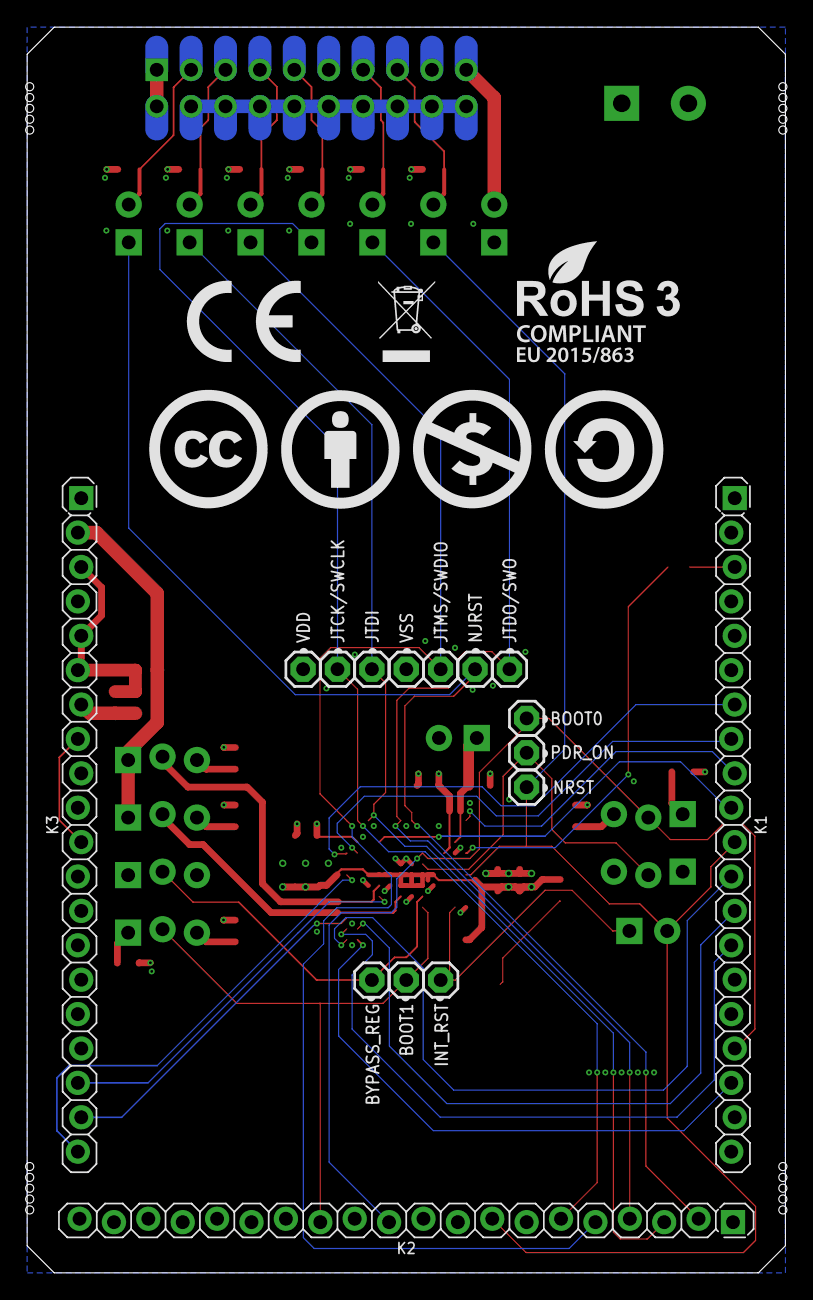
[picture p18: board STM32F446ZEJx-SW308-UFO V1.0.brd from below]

Board: 4 copper layers, 56.0 x 92.0 mm, 85 parts (20 on the bottom side), 46 nets.

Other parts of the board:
U$1: 1234_MULTI-LAYER_PCB-INSPECTION
U$2: GITHUB_ARCADEHUSLE_PROJECTLITTLEMAN_2_BOTTOM_45MM
U$3: GITHUB_ARCADEHUSLE_PROJECTLITTLEMAN_2_TOP_45MM
U$4: CE_ICON_6MM
U$5: WEEE_ICON_6MM
U$6: ROHS3_COMPLIANT_ICON_6MM-8.98MM
U$8: ICON_CC-BY-NC-SA-4.0_H=8.7MM

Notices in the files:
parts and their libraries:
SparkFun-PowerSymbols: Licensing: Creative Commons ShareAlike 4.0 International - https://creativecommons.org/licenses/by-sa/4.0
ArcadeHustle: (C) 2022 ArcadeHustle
